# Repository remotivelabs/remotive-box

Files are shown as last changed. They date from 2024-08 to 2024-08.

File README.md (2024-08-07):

# RemotiveBox

[RemotiveBroker](https://remotivelabs.com) runs on the hardware of your choice. We have a growing list of [reference kits](https://remotivelabs.com/downloads-documentations/#section-referense-kit)
to ensure that getting started is quick and simple.

Here you can find STL files to print your own RemotiveBox.

Simply import the files from the folder [3D-model/STL](3D-model/STL) into your favorite 3D printer/slicing tool.

## Components

- Raspberry Pi 4 (4GB)
- [Seeed Studio](https://wiki.seeedstudio.com/2-Channel-CAN-BUS-FD-Shield-for-Raspberry-Pi/)
- Mounting kit (D-SUB mountings), [41011082](https://www.electrokit.com/en/product/mounting-kit-d-sub-13mm/)
- Rubber foot, [41001130](https://www.electrokit.com/en/product/rubber-foot-11x5-mm/)

A PCB has been developed to connect the D-sub and banana connectors to the Raspberry Pi inside the box. This PCB can be produced and assebled by [jlcpcb.com](https://cart.jlcpcb.com/quote) by uploading the [gerber files](Adapter_PCB_/Gerber). 
The banana connectors need to be purchased and soldered separetely from  [farnell.com](https://www.farnell.com)
- [Red](https://se.farnell.com/multicomp/24-243-1/banana-socket-20a-4mm-pcb-red/dp/1698982?ICID=I-HP-STM7REC-RP-3)
- [Black](https://se.farnell.com/multicomp/24-243-2/receptacle-20a-4mm-pcb-solder/dp/1698983)

## Gallery

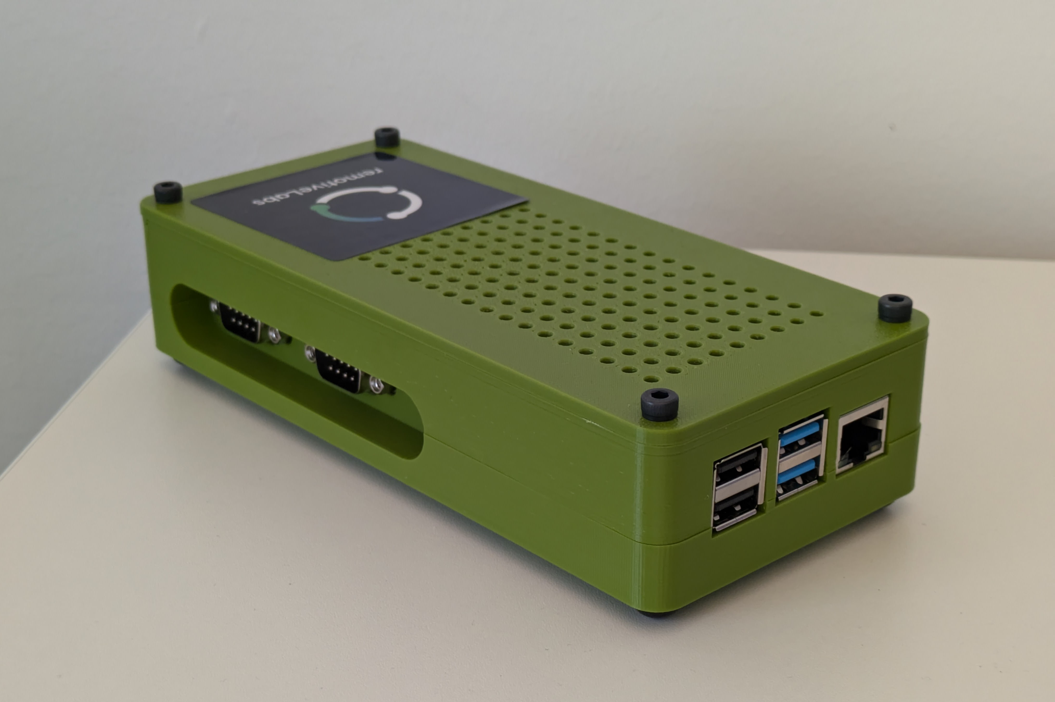
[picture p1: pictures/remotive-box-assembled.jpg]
RemotiveBox Assembled

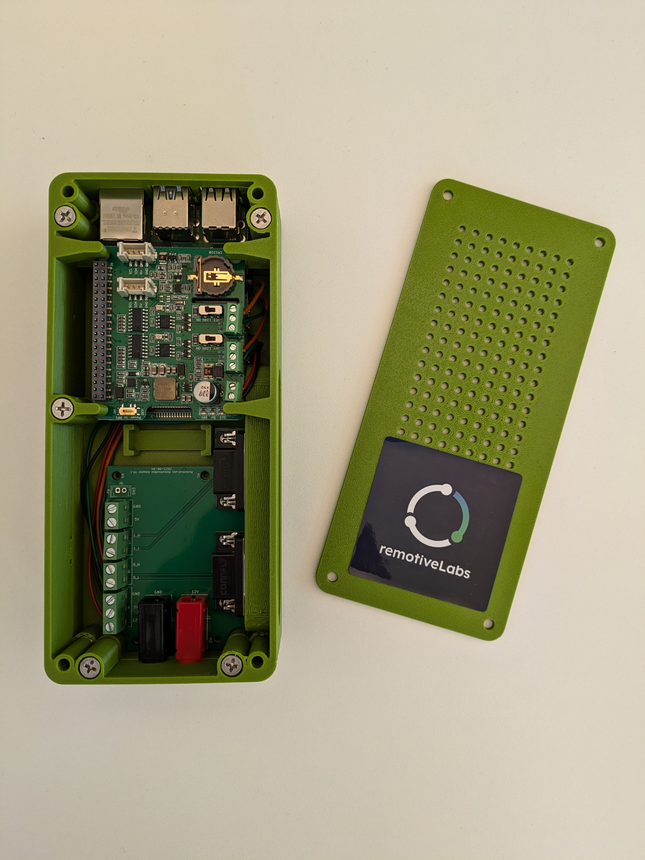
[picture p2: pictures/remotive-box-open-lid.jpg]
RemotiveBox Internals


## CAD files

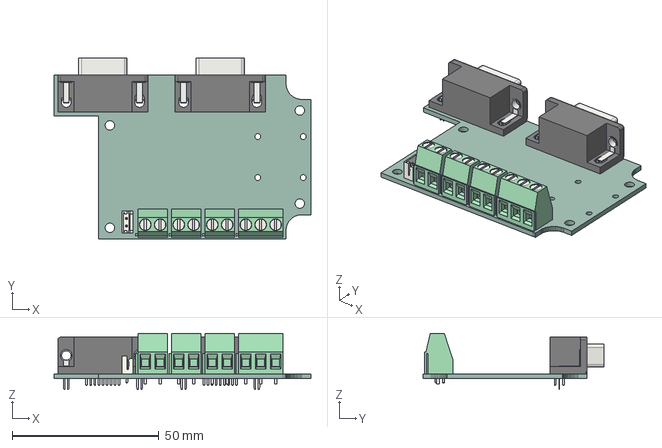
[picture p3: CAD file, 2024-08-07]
3D-model/Alibre 3D Cad/Adapter Card/Adapter Card.step
87.6 x 61.7 x 19.2 mm
Box PCB

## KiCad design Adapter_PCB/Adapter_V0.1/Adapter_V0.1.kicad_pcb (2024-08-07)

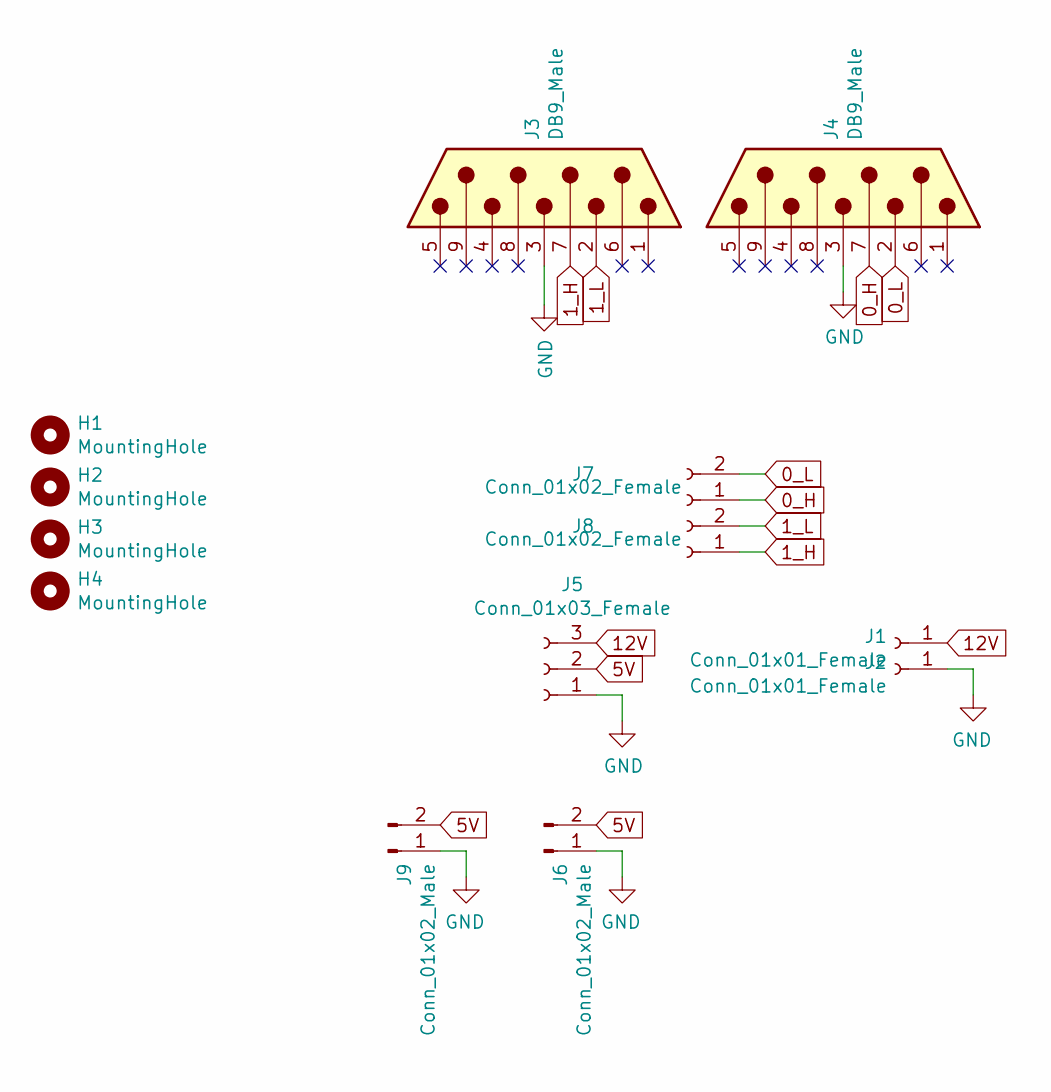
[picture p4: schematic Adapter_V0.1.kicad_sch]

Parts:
H1, H2, H3, H4: MountingHole; MountingHole_3.2mm_M3
J1, J2: Conn_01x01_Female; Banana_Jack
J3, J4: DB9_Male; DSUB-9_Male_Horizontal_P2.77x2.84mm_EdgePinOffset7.70mm_Hou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
J5: Conn_01x03_Female; TerminalBlock_Phoenix_MKDS-1,5-3-5.08_1x03_P5.08mm_Horizont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
J6: Conn_01x02_Male; JST_EH_B2B-EH-A_1x02_P2.50mm_Vertical
J7, J8: Conn_01x02_Female; TerminalBlock_Phoenix_MKDS-1,5-2-5.08_1x02_P5.08mm_Horizont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
J9: Conn_01x02_Male; TerminalBlock_Phoenix_MKDS-1,5-2-5.08_1x02_P5.08mm_Horizont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

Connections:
0_H: J4.7, J7.1
0_L: J4.2, J7.2
1_H: J3.7, J8.1
1_L: J3.2, J8.2
5V: J5.2, J6.2, J9.2
12V: J1.1, J5.3
GND: J2.1, J3.3, J4.3, J5.1, J6.1, J9.1

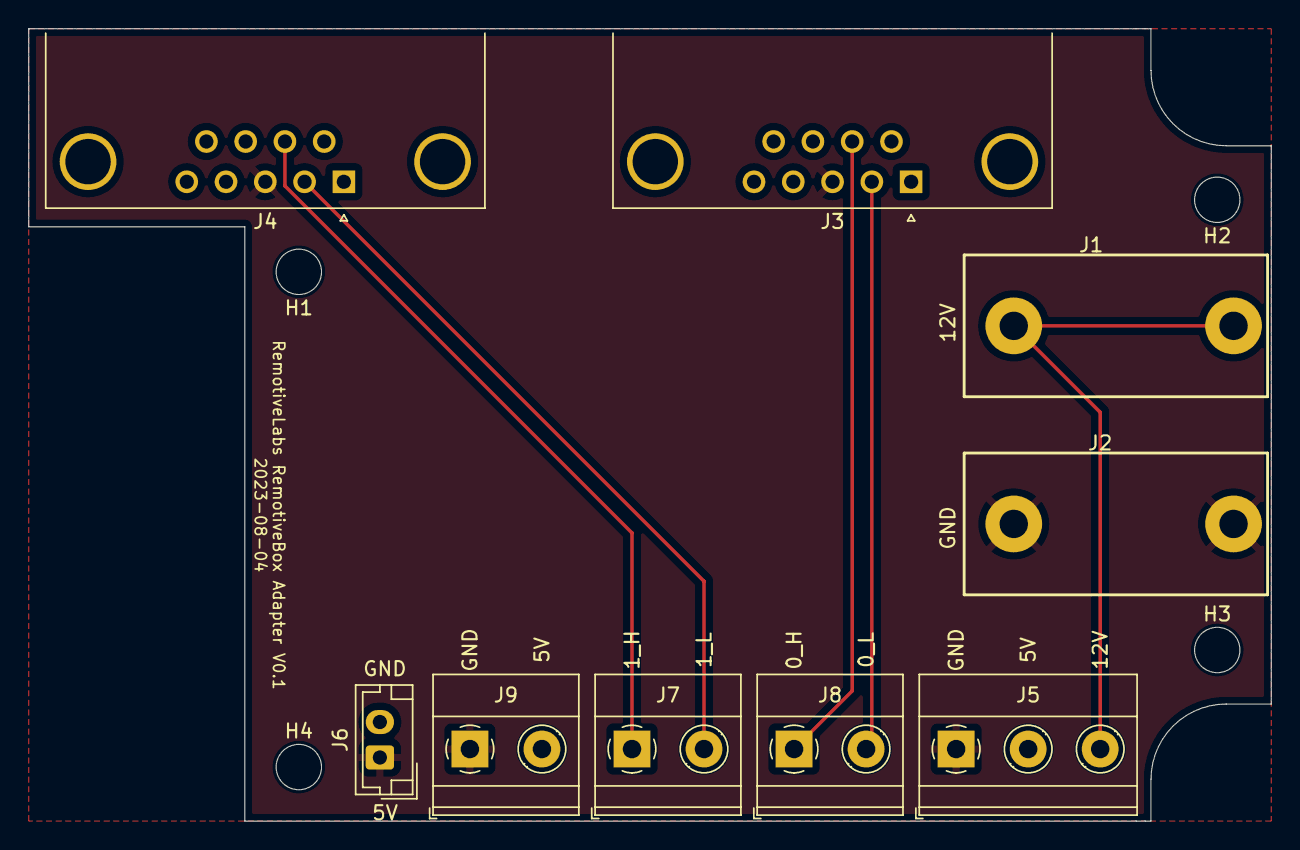
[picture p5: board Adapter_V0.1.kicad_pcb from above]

Board: 2 copper layers, 87.6 x 55.9 mm, 13 parts (0 on the bottom side), 7 nets.

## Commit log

2023-03-13 Remotive Box DIY 3D kit documentation
    A copy of contents from the deprecated repository
    https://github.com/beamylabs/beamylabs-start/tree/master/beamyone/
    [Remotive Box - bottom 220110.stl, Remotive Box - lid 220110.stl, Remotive Box - top 220110.stl]
2024-08-07 Added adapter PCB files and new 3d models, and removed the old ones. The was changed accordingly
    [Remotive Box - bottom 220110.stl, Remotive Box - lid 220110.stl, Remotive Box - top 220110.stl]
